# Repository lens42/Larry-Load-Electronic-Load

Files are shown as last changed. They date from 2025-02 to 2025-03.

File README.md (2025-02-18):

This simple electronic load for testing power supply circuits was a popular lab-built piece of test gear at Maxim Integrated Products. It came to be known as the "Larry Load" by the lab rats at Maxim, because the design originated from an applications engineer named Larry Carr. Commercial electronic loads were available from companies like Kikusui, but those were not cheap (while Maxim famously *was* back then) and Larry Loads were unique in their simplicity, wide range, and every-day utility. After retiring from Maxim. I had always intended to build a few of these for home lab use. I finally did just that.

3D files for the case include only the top section. Features are cut into a 3" section of 4"x2" alumimum U-channel. The bottom half is the same as the top, but without the pockets and the mounting holes for MOSFETs.

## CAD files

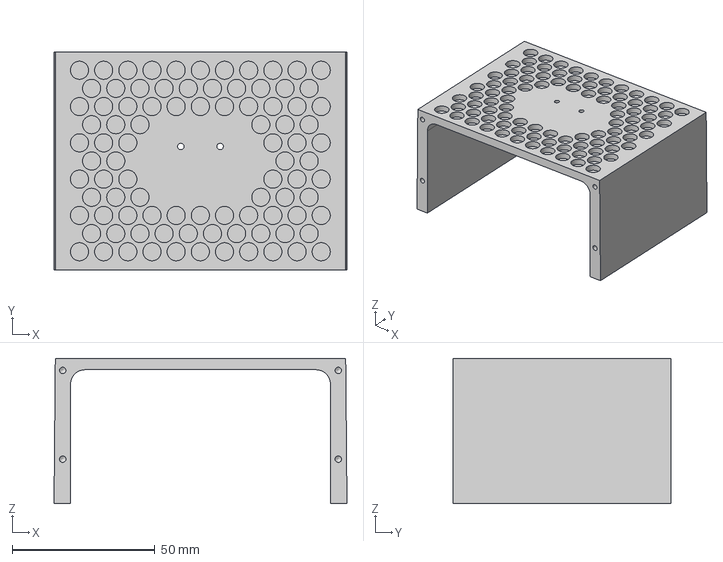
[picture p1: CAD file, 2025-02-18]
case top half.step
102.5 x 76.2 x 50.8 mm

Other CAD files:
case top half.f3d

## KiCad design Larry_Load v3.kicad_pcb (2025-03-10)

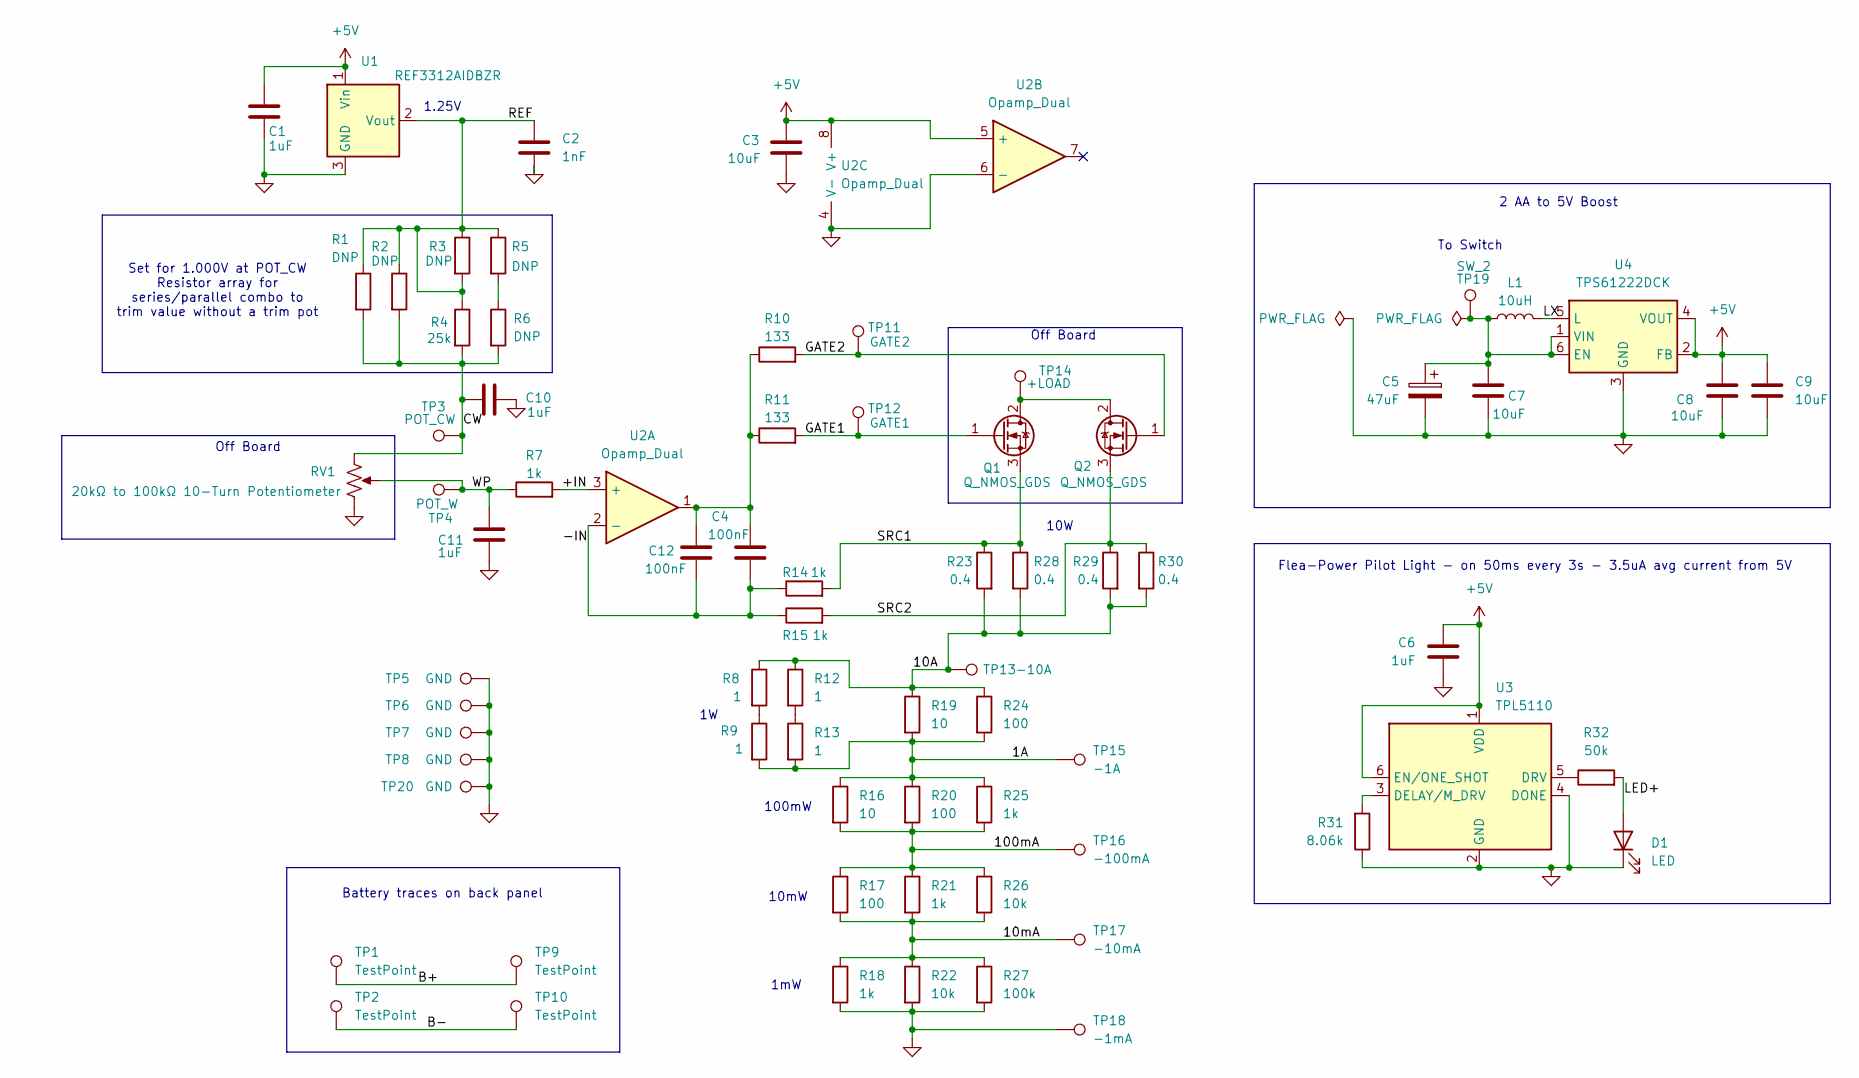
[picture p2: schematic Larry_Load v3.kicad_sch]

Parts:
C1, C6, C10, C11: 1uF; C_0805_2012Metric_Pad1.18x1.45mm_HandSolder
C2: 1nF; C_0805_2012Metric_Pad1.18x1.45mm_HandSolder
C3, C7, C8, C9: 10uF; C_1206_3216Metric_Pad1.33x1.80mm_HandSolder
C4, C12: 100nF; C_0805_2012Metric_Pad1.18x1.45mm_HandSolder
C5: 47uF; CP_Elec_6.3x7.7
D1: LED; LED_VLDTG1232R-08_ReverseMount
L1: 10uH; L_Cenker_CKCS5020
Q1, Q2: Q_NMOS_GDS
R1, R2, R3, R5, R6: DNP; R_1206_3216Metric_Pad1.30x1.75mm_HandSolder
R4: 25k; R_1206_3216Metric_Pad1.30x1.75mm_HandSolder
R7, R14, R15, R18, R21, R25: 1k; R_1206_3216Metric_Pad1.30x1.75mm_HandSolder
R8, R9, R12, R13: 1; R_1206_3216Metric_Pad1.30x1.75mm_HandSolder
R10, R11: 133; R_1206_3216Metric_Pad1.30x1.75mm_HandSolder
R16, R19: 10; R_1206_3216Metric_Pad1.30x1.75mm_HandSolder
R17, R20, R24: 100; R_1206_3216Metric_Pad1.30x1.75mm_HandSolder
R22, R26: 10k; R_1206_3216Metric_Pad1.30x1.75mm_HandSolder
R23, R28, R29, R30: 0.4; R_2512_6332Metric_Pad1.40x3.35mm_HandSolder
R27: 100k; R_1206_3216Metric_Pad1.30x1.75mm_HandSolder
R31: 8.06k; R_1206_3216Metric_Pad1.30x1.75mm_HandSolder
R32: 50k; R_1206_3216Metric_Pad1.30x1.75mm_HandSolder
RV1: 20kΩ to 100kΩ 10-Turn Potentiometer
TP1, TP2, TP9, TP10: TestPoint; TestPoint_Pad_4.0x6.0mm
TP3: POT_CW; TestPoint_Pad_4.0x6.0mm
TP4: POT_W; TestPoint_Pad_4.0x6.0mm
TP5, TP6, TP7, TP8, TP20: GND; TestPoint_Pad_4.0x6.0mm
TP11: GATE2; TestPoint_Pad_4.0x6.0mm
TP12: GATE1; TestPoint_Pad_4.0x6.0mm
TP13: -10A; MountingHole_5.3mm_M5_DIN965_Pad_TopBottom
TP14: +LOAD; TestPoint_Pad_4.0x6.0mm
TP15: -1A; MountingHole_5.3mm_M5_DIN965_Pad_TopBottom
TP16: -100mA; MountingHole_5.3mm_M5_DIN965_Pad_TopBottom
TP17: -10mA; MountingHole_5.3mm_M5_DIN965_Pad_TopBottom
TP18: -1mA; MountingHole_5.3mm_M5_DIN965_Pad_TopBottom
TP19: SW_2; TestPoint_Pad_4.0x6.0mm
U1: REF3312AIDBZR; SOT-23
U2: Opamp_Dual; SO-8_3.9x4.9mm_P1.27mm
U3: TPL5110; SOT-23-6
U4: TPS61222DCK; Texas_R-PDSO-G6

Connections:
+5V: C1.1, C3.1, C6.2, C8.1, C9.1, U1.1 (Vin), U2.5 (+), U2.8 (V+), U3.1 (VDD), U3.6 (EN/ONE_SHOT), U4.2 (FB), U4.4 (VOUT)
/1A: R9.2, R13.2, R16.1, R19.2, R20.1, R24.2, R25.1, TP15.1
/10A: R8.1, R12.1, R19.1, R23.2, R24.1, R28.2, R29.2, R30.2, TP13.1
/10mA: R17.2, R18.1, R21.2, R22.1, R26.2, R27.1, TP17.1
/100mA: R16.2, R17.1, R20.2, R21.1, R25.2, R26.1, TP16.1
/+IN: R7.2, U2.3 (+)
/-IN: C4.2, C12.2, R14.1, R15.1, U2.2 (-)
/B+: TP1.1, TP9.1
/B-: TP2.1, TP10.1
/CW: C10.1, R1.2, R2.2, R4.2, R6.2, RV1.1, TP3.1
/GATE1: Q1.1 (G), R11.2, TP12.1
/GATE2: Q2.1 (G), R10.2, TP11.1
/LED+: D1.2 (A), R32.2
/LX: L1.2, U4.5 (L)
/REF: C2.1, R1.1, R2.1, R3.1, R3.2, R4.1, R5.1, U1.2 (Vout)
/SRC1: Q1.3 (S), R14.2, R23.1, R28.1
/SRC2: Q2.3 (S), R15.2, R29.1, R30.1
/WP: C11.1, R7.1, RV1.2, TP4.1
GND: C1.2, C2.2, C3.2, C5.2, C6.1, C7.2, C8.2, C9.2, C10.2, C11.2, D1.1 (K), R18.2, R22.2, R27.2, R31.1, RV1.3, TP5.1, TP6.1, TP7.1, TP8.1, TP18.1, TP20.1, U1.3 (GND), U2.4 (V-), U2.6 (-), U3.2 (GND), U3.4 (DONE), U4.3 (GND)
unnamed: C4.1, C12.1, R10.1, R11.1, U2.1
unnamed: Q1.2 (D), Q2.2 (D), TP14.1
unnamed: R5.2, R6.1
unnamed: R8.2, R9.1
unnamed: R12.2, R13.1
unnamed: R31.2, U3.3 (DELAY/M_DRV)
unnamed: R32.1, U3.5 (DRV)
unnamed: C5.1, C7.1, L1.1, TP19.1, U4.1 (VIN), U4.6 (EN)

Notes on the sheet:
Off Board
1.25V
10mW
10W
To Switch
Flea-Power Pilot Light - on 50ms every 3s - 3.5uA avg current from 5V
1mW
100mW
Battery traces on back panel
2 AA to 5V Boost
Set for 1.000V at POT_CW Resistor array for series/parallel combo to trim value without a trim pot

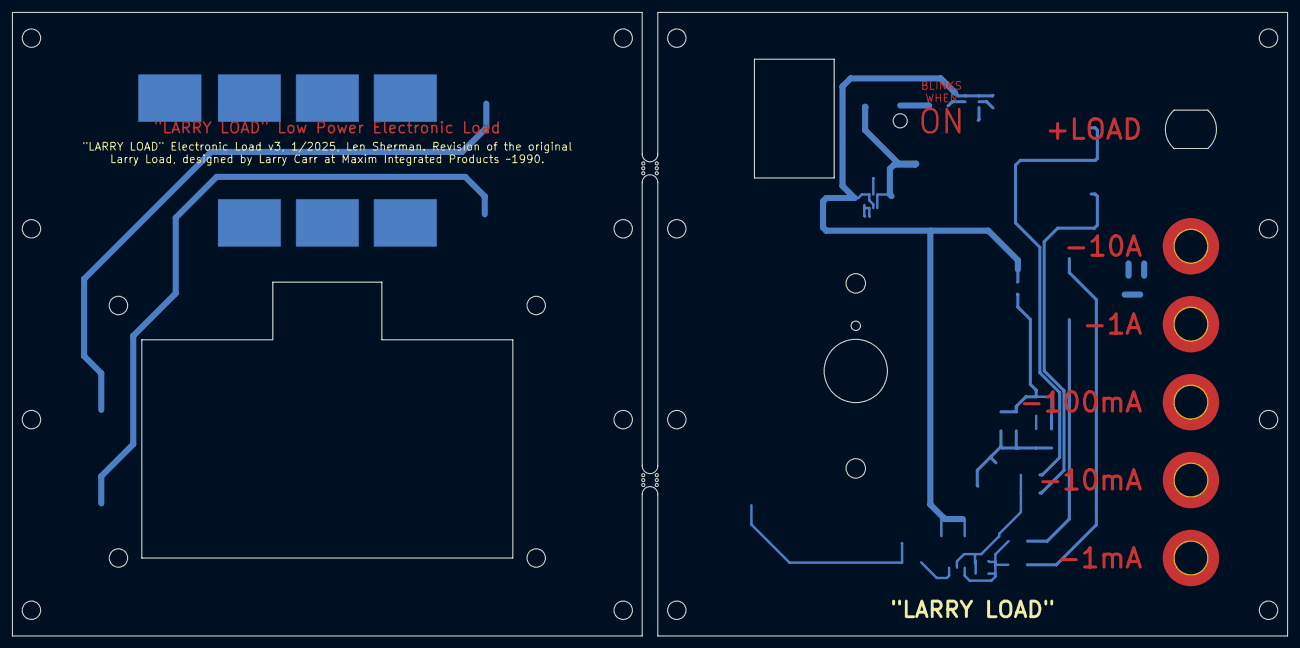
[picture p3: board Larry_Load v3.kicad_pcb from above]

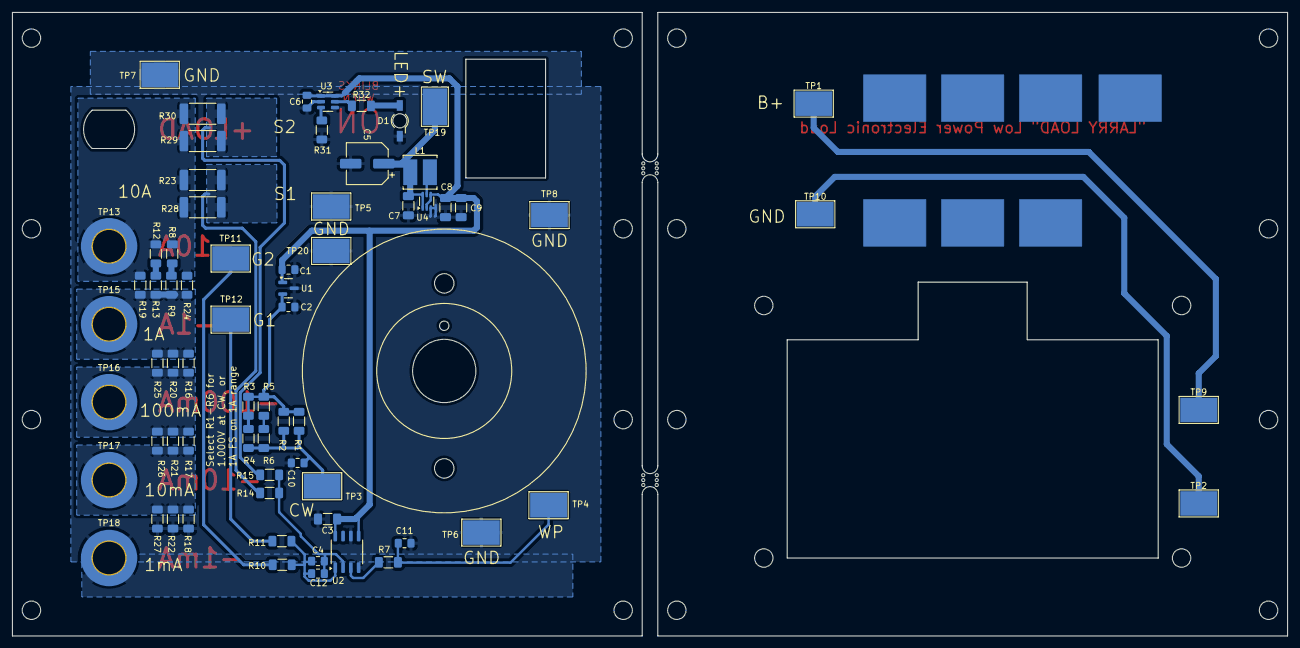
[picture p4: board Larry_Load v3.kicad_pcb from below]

Board: 2 copper layers, 207.8 x 101.6 mm, 71 parts (69 on the bottom side), 26 nets.

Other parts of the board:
mouse-bite-2.54mm-slot, mouse-bite-2.54mm-slot#2: VAL**; mouse-bite-2.54mm-slot

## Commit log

2025-02-18 Add files via upload
    Adding 3D files for the case top. Bottom is same file without some of the features.
    [case top half.f3d, case top half.step]
2025-03-10 Add files via upload
    Fixed incorrect values for LED blinker
    [Larry_Load v3.kicad_sch]
2025-03-10 Add files via upload
    Fixed incorrect values for R31, R32
    [Larry_Load v2.kicad_sch, Larry_Load v3.kicad_pcb]
